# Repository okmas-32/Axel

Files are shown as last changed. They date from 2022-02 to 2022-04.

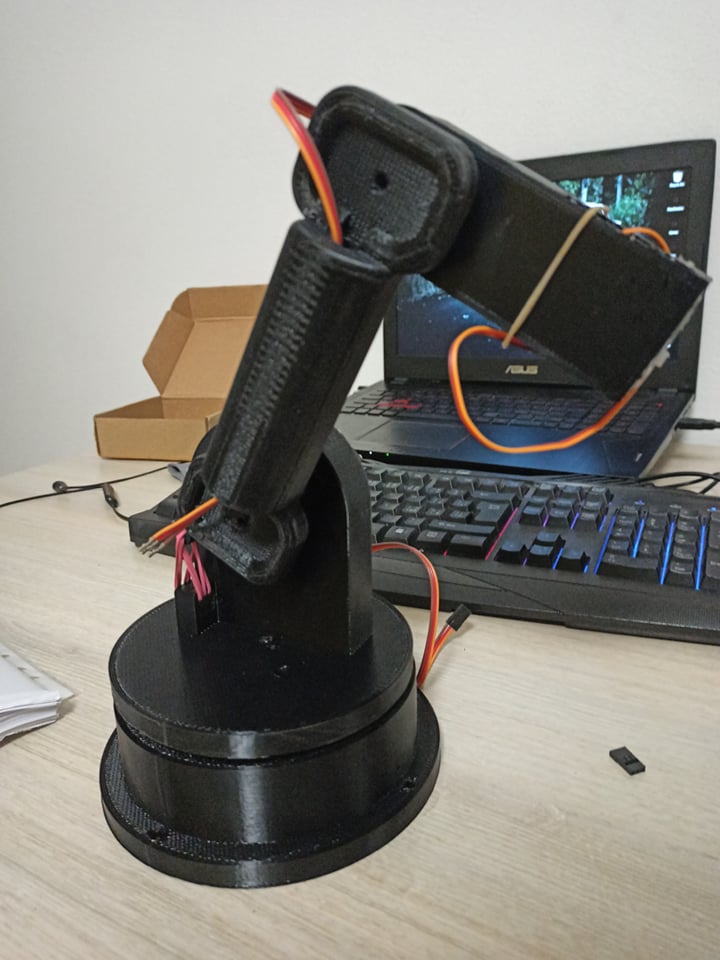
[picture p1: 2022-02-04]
3D_models/Angie_V1/Angie.jpg

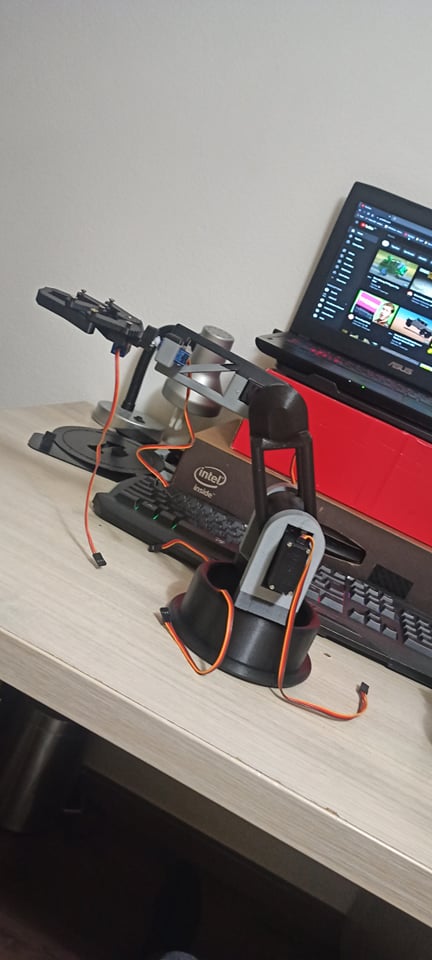
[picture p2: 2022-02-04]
3D_models/Bimbis_V2/Bimbis.jpg

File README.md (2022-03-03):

# Axel

It's our (me and my friend) graduation project about 3D printed robotic hands and they controlled by RaspberryPi-Arduino combo

we are using:
1. Raspberry Pi 3 b+		[`link`](https://www.raspberrypi.com/products/raspberry-pi-3-model-b-plus/) *1
1. Arduino Uno		[`link`](https://techfun.sk/produkt/arduino-uno-r3-precizny-klon/)  *2
1. Arduino Nano			[`link`](https://techfun.sk/produkt/arduino-nano-precizny-klon/)  *1
1. Servo motorček SG90		[`link`](https://techfun.sk/produkt/servo-motorcek-sg90/)   *3
1. Servo motorček MG996R	[`link`](https://techfun.sk/produkt/servo-motorcek-mg996r/) *7 
1. Buttons			[`link`](https://techfun.sk/produkt/tlacidlo-pbs-110-momentove-normalne-otvorene/)  *5
1. 2 axis joystick		[`link`](https://techfun.sk/produkt/joystick-2-osi-analogovy-vystup/) *2

how i set up Raspberry pi and its hotspot in RP_info.txt

python code works on linux and on windows (i dont know about mack)

how [`Angie`](/3D_models/Angie_V1/Angie.jpg) looks like :raised_hand_with_fingers_splayed:

how [`Bimbis`](/3D_models/Bimbis_V2/Bimbis.jpg) looks like :mechanical_arm:

---

Dominik Mankovický,
Samuel Čápek

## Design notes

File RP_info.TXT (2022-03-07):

všetok aktuálny kód je na stránke https://github.com/okmas-32/Axel

postup:

	nainštalovanie:
		pythonu 3.9.5:
			https://itheo.tech/install-python-39-on-raspberry-pi

		mounting USB:
			https://raspberrytips.com/mount-usb-drive-raspberry-pi/

		pip3.9:
			popen
			serial
			pyserial (kvôli serial.tools.list_ports ale to nefungovalo na raspberry tak som nakoniec použil popen)

-note: musel som spraviť work around lebo žiadna knižnica mi nevypíše výrobcu každého USB pripojeného zariadenia tak som spravil to že napíšem každému zariadeniu a to ktoré správne odpovie naspäť bude brané ako Arduino

	wireless access point (wireless controll):
		https://www.raspberryconnect.com/projects/65-raspberrypi-hotspot-accesspoints/158-raspberry-pi-auto-wifi-hotspot-switch-direct-connection
		-ssid: AXEL_WiFi (2)
		-pass: (take iste ako ssh heslo)

	joistick (do budúcna):
		https://iot-guider.com/raspberrypi/analog-joystick-module-in-raspberry-pi/attachment/interfacing-analog-joystick-module-in-raspberry-pi/

impruve:
	stránka
	Bézier Curve (3 bodové krivky ktoré sa tiež používajú na zobrazovanie fondow)
		-GIF		https://ambrosiogabe.github.io/assets/images/mathBehindFonts/bezierMath.gif
		-stránka	https://ambrosiogabe.github.io/the-math-behind-font-rasterization/
		-video		https://www.youtube.com/watch?v=LaYPoMPRSlk
	tutorial na pomali vsetko co treba vylepsit:
		-https://www.societyofrobots.com/robot_arm_tutorial.shtml

	viem že je možné z Raspberry pi programovať Arduino neskôr sa na to pozriem

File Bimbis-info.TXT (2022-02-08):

dĺžky:
	Base:		52mm
	Waist:		65mm
	Arm1:		150mm
	Arm2:		115mm
	Nastroj:	100mm

servo note:
	dve servá sú oproti sebe tak jedno z nich terba rozlíšiť (nazval som ho angry twin) a tomu servu treba prepočítať uhol "opačne" oproti jeho normálnej dvojičke vzhľadom k ich maximu (čo je 180°)
	v realite je servo označené bielymi botkami
	inými slovami:
		servo twin write(pos)
		servo angry_twin write(180 - pos)

motory (servos):

	Servo Motor MG996R (4ks)
		Operating Voltage is +5V typically
		Running Current:	500-900mA (6V)
		Stall Current:		2.5A (6V)
		Stall Torque: 		9.4 kg/cm (at 4.8V)
		Maximum Stall Torque: 	11 kg/cm (6V)
		Operating speed:	0.17 s/60° (1°/~3ms)
		Gear Type: 		Metal
		Rotation: 		0°-180°
		Weight of motor: 	55gm
	
	Servo Motor Micro SG90 (1ks)
		Voltage:		4.8-6VDC  (5V Typical)
		Current (stall):	360mA (measured) (idle 10mA)
		Stall Torque:		1.7 kg-cm (measured)
		Operating Speed:	0.12s / 60° (varies with VDC)
		Gear Type: 		Plastic
		Rotation: 		0°-180°

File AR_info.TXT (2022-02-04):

arduino je použité ako ovládač hardwaru... to jesť samotné servá na ruke

v programe som nikde nepoužil delay() dôvod:	
	-zastavý to celé arduino na dobu ktorý mu dám
	-radšej som si spravil vlastnú 
	-radšej som si spravil vlastnú funkciu ckaj()

musel som použiť baudrate 115200 inak by to nestíhalo taký veľký nával dát naraz (posielam cca 40ch raz a potom čakám)

!!!Arduino nano používa ATmega328P (old bootloader)

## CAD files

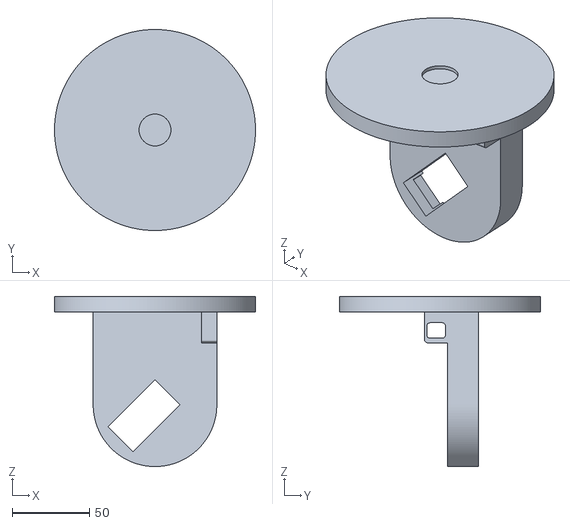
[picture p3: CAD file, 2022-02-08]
3D_models/Angie_V1/Waist.stl
130.0 x 130.0 x 110.0

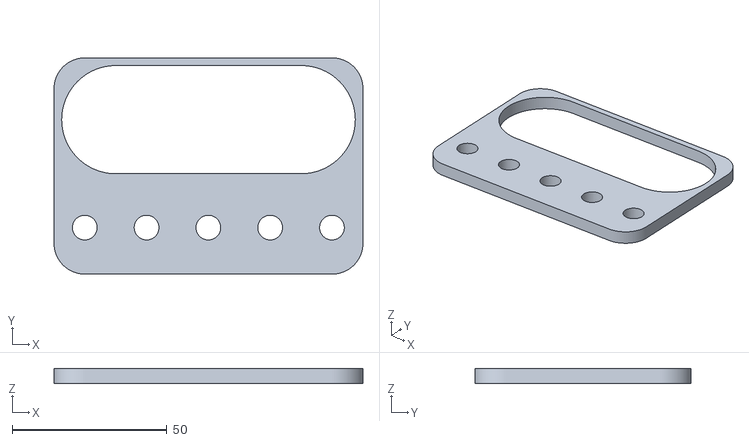
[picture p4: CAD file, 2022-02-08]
3D_models/Auxiliary_Stuff/Joy_housing_top.stl
100.0 x 70.0 x 5.00

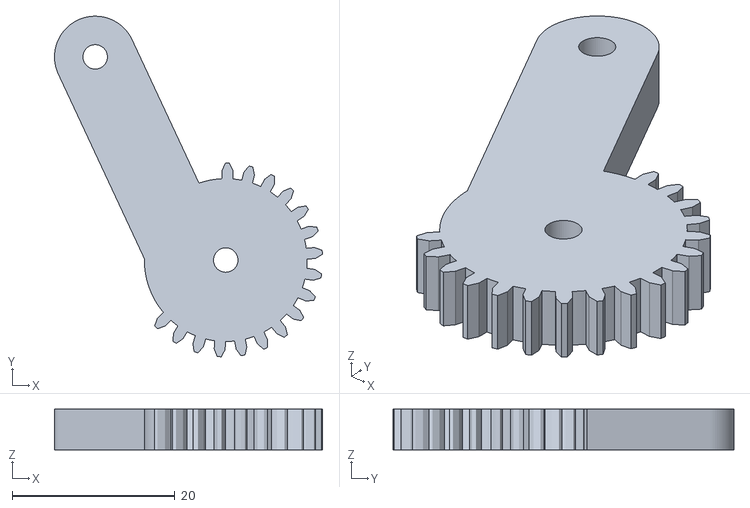
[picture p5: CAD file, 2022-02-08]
3D_models/Bimbis_V2/Gripper/Gripper Gear.stl
32.9 x 41.8 x 5.00

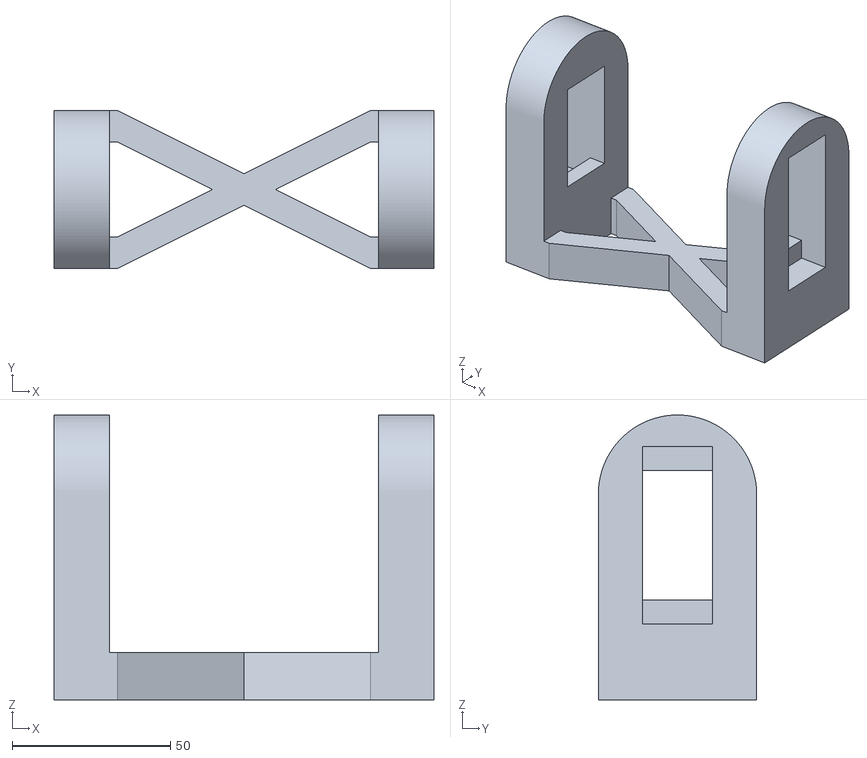
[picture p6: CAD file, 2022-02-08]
3D_models/Bimbis_V2/Waist.stl
120.0 x 50.0 x 90.0

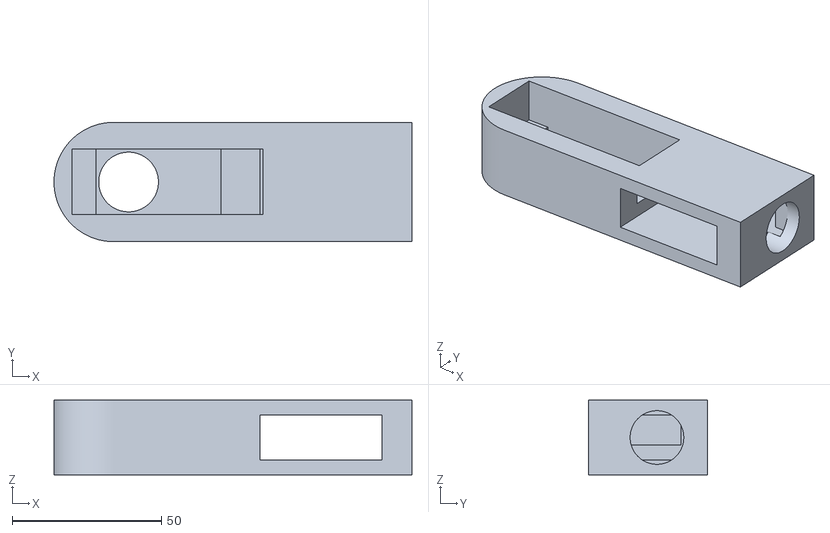
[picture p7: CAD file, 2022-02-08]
3D_models/Angie_V1/Forearm.stl
120.0 x 40.0 x 25.0

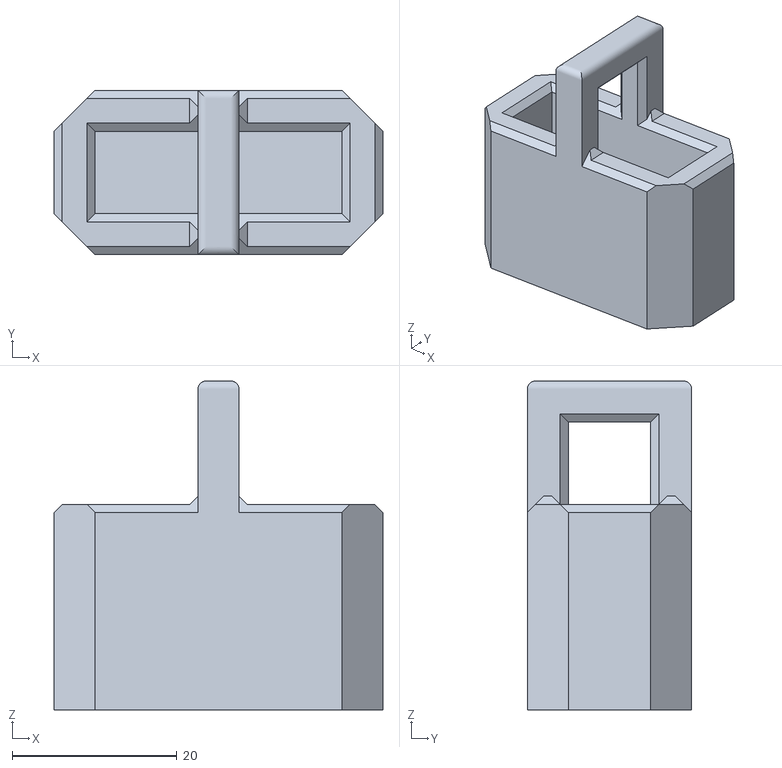
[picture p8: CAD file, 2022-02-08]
3D_models/Auxiliary_Stuff/A focking bocket.stl
40.0 x 20.0 x 40.0

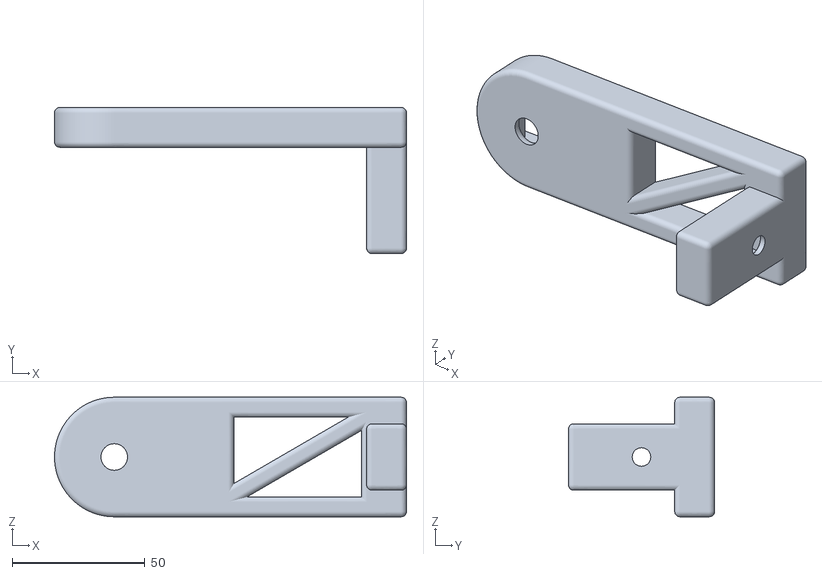
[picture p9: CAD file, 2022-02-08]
3D_models/Bimbis_V2/Forearm.stl
132.5 x 55.0 x 45.0

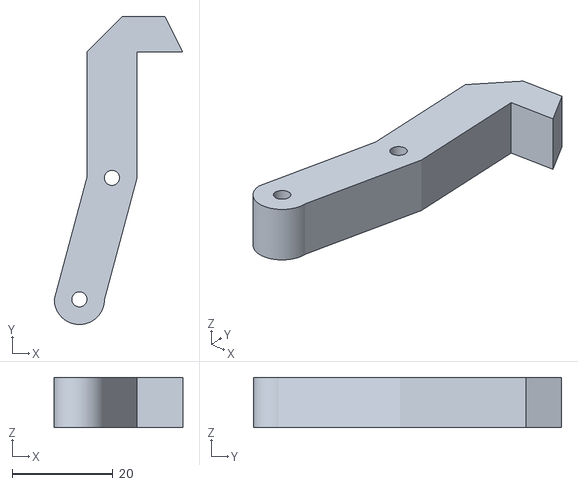
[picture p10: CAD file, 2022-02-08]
3D_models/Bimbis_V2/Gripper/Gripper claw2.stl
25.5 x 61.2 x 10.0

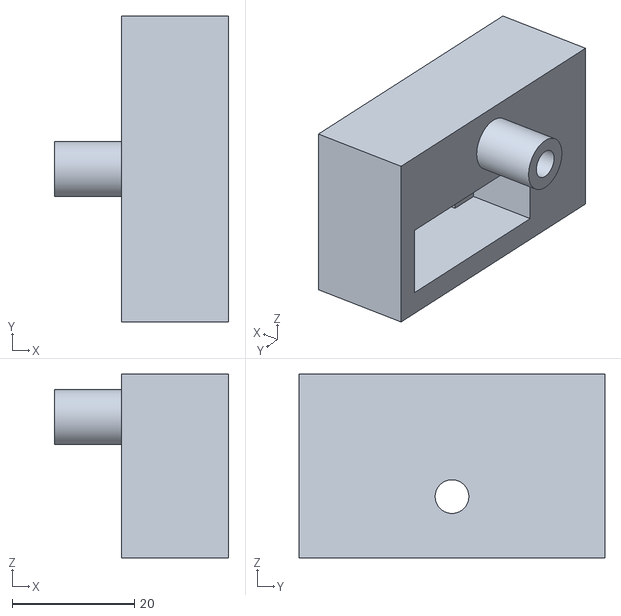
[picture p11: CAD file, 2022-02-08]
3D_models/Angie_V1/Gripper base.stl
28.5 x 50.0 x 30.0

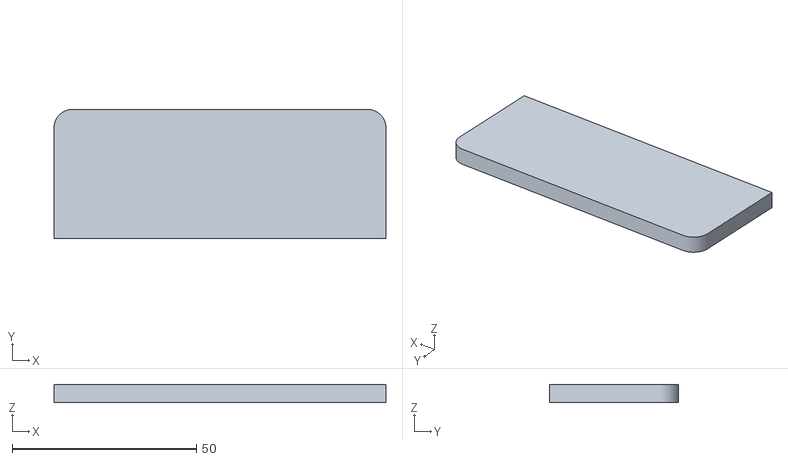
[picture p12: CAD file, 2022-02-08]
3D_models/Auxiliary_Stuff/Joy_spacer.stl
90.0 x 35.0 x 5.00

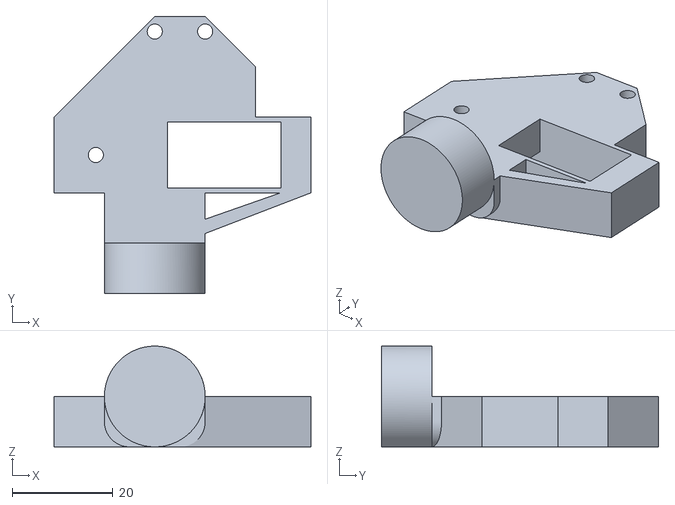
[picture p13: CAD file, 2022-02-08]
3D_models/Bimbis_V2/Gripper/Gripper base.stl
51.0 x 55.0 x 20.0

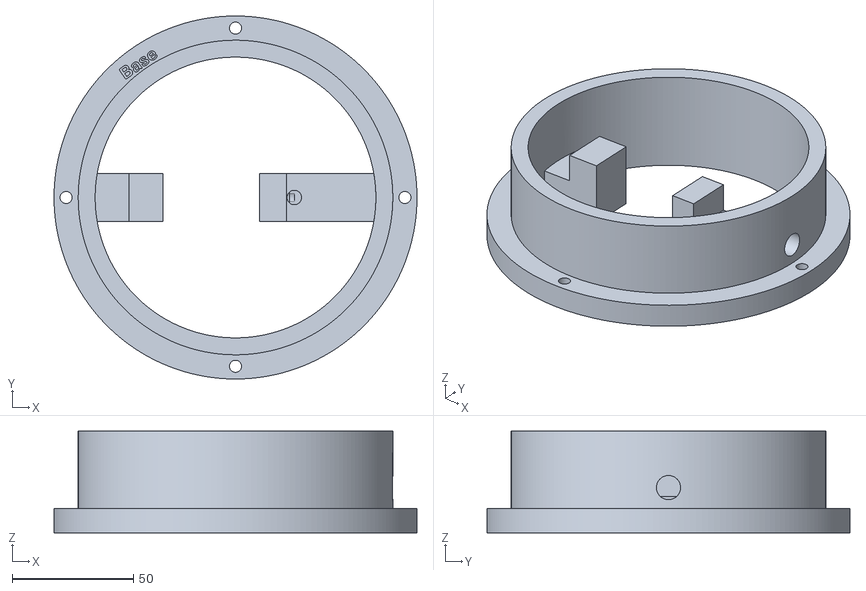
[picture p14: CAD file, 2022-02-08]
3D_models/Angie_V1/BAse.stl
150.0 x 150.0 x 42.0

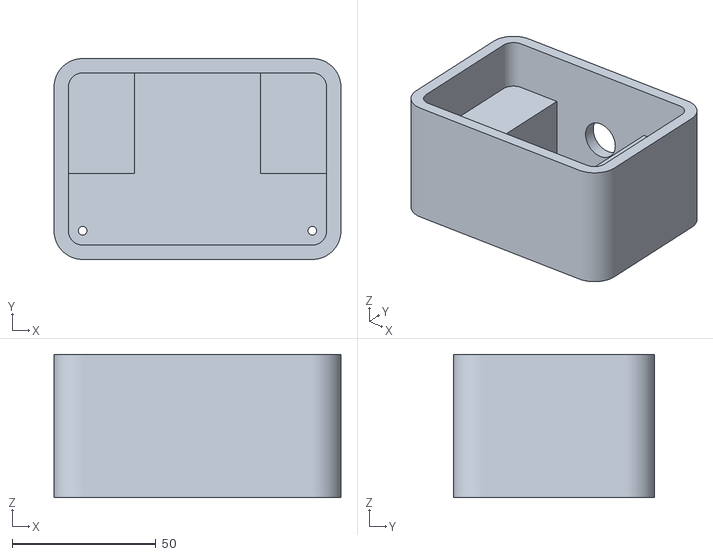
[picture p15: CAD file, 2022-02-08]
3D_models/Auxiliary_Stuff/Joy_housing.stl
100.0 x 70.0 x 50.0

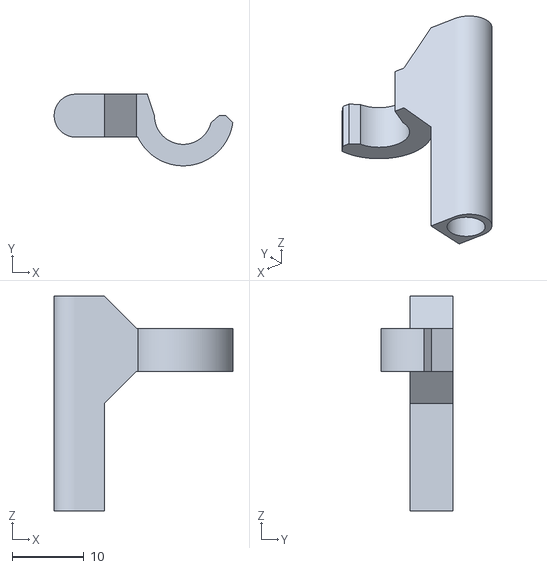
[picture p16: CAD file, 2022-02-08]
3D_models/Angie_V1/Gripper hook.stl
24.9 x 10.00 x 30.0

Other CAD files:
3D_models/Bimbis_V2/Gripper/Gripper claw.stl
3D_models/Bimbis_V2/Gripper/Griper gear 2.stl
3D_models/Bimbis_V2/Gripper/Gripper link 2.stl
3D_models/Bimbis_V2/Gripper/Gripper link.stl

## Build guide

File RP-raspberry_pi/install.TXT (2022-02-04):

pip install serial-tool
pip install serial

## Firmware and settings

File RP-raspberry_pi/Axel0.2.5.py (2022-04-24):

import subprocess
import sys
import serial
import serial.tools.list_ports  # python -m serial.tools.list_ports -v
import time
import locale
from math import sqrt, atan2, degrees
from csv import DictReader

baud_rate = 115200
spacer = ","

# TODO spraviť nejakú funkciu na debug
debug = {
	'0':            bool(1),  # celkový debug
	'csv':          bool(1),  # čítanie CSV súboru
	'math':         bool(1),  # matematika
	'mathEX':       bool(0),  # matematika
	'ini':          bool(1),  # inicializačný
	'fromser':      bool(1),  # z sériového portu
	'auto-program': bool(1),  # proste automatický mód
	'zasielanie':   bool(1),  # kontrola zasielania
	'text':         '\x1b[1;33;33m' + 'debug:' + '\x1b[0m',  # samotný text "debug:"
	'space':        '\x1b[1;33;33m' + 'I ' + '\x1b[0m',  # žltý medzerník
	'gtext':        '\33[92m' + 'I ' + '\33[0m',  # zelený medzerník
	'Error':        '\x1b[1;30;41m' + '\tE ' + '\x1b[0m'  # VEĽKÉ červené "E "
}


class OSErr(OSError):
	pass


class CustomError(Exception):
	"""môj vlastný error handler.. spravil som ho hľavne kvôli tomu
     aby som vedel zachitiť errori ale aj kvôli tomu že to bola sranda naprogramovať"""

	# zachitím error a vypíšem ho bez toho aby som musel zastaviť celí
	# program a robiť odznova celú inicializáciu a podobne

	# teda ak je to error ktorý som schopný obýsť.. ak to je niečo fatálnejšie tak to crashne celé
	def __init__(self, exception, i=None):
		if i != None:
			# ak to je očakávaný error (bez veľkého červeného E na začiatku)
			print('\r' + debug['space'] + str(exception))
		else:
			i = None
			print('\r' + debug['space'] + debug['Error'] + str(exception))
		pass


def tiME(func):
	def MYtiME(*args, **kwargs):
		t1 = time.time()
		nic = func(*args, **kwargs)
		t2 = time.time()
		print('\033[33m' + f'Function {func.__name__!r} executed in {(t2 - t1):.4f}s' + '\033[0m' + '\r\n')
		return nic

	return MYtiME


def wrapp(func):
	def MYwrapp(*args, **kwargs):
		print('\033[36m' + '*' * 20 + '\033[0m')
		func(*args, **kwargs)
		print('\033[36m' + '*' * 20 + '\033[0m')

	return MYwrapp


class Axel():
	def __init__(self, poss):
		"""tu si iba určím aké parametre bude držať objekt v
        classe Axel ako napr. port v ktorom je Arduino alebo dĺžku ramena ruky"""

		self.u1 = 0
		self.u2 = 0
		self.u3 = 0
		self.u4 = 0

		# ports in string
		self.Aport = False
		self.Bport = False
		self.joyPort = False

		self.notAxel = []

		self.pos1 = {}
		self.pos2 = {}

		if __name__ == "__main__":  # prečíta automaticky csv len ak je spustený ako hlavný program
			self.CSVr(poss)

			if debug['csv']:
				print(debug['gtext'] + debug['text'] + f' CSV-saved↓ \r')
				print(f'\t{self.pos1}')
				print(f'\t{self.pos2}')
				print(f'počet príkazov z CSV pre 1: {len(self.pos1)}')
				print(f'počet príkazov z CSV pre 2: {len(self.pos2)}')
				print('\r')

		self.X = 300
		self.Y = 250
		self.Z = 0

	# inicializácia
	# self.ini()

	# toto mám iba na testovanie Arduina
	#                      ↓↓ čas na pohyb v milisekundách
	# -3689,7823,14682,25,500
	# -3689,7823,14682,25,25,500

	# self.mathAX2(self.X, self.Y, self.Z, 143, 96, 7)

	def mathAX2(self, Xi, Yi, Zi, arm1, arm2, tool, base, Xbase=0, Ybase=0, Zbase=0):
		"""matika na výpočet uhlov z súradníc pre 2kĺbového robota + výpočet rotácie základne
         s Z (roboj je v zmysle že je položený a pracovnú plochu má okolo seba)"""
		# TODO niekedy optimalizovať
		# TODO spraviť pre celé pracovisko (offsety)

		# note base predpokladám že bude súčet base a waist (pre matiku to je v podsatate iba offset od "zeme")
		if debug['math'] and debug['mathEX']:
			print(debug['text'] + f' Matika-neznáme↓')
			print(f'\t_X = {Xi}')
			print(f'\t_Y = {Yi}')
			print(f'\t_Z = {Zi}')
			print(f'\tbase = {base}')
			print(f'\tarm1 = {arm1}')
			print(f'\tarm2 = {arm2}')
			print(f'\ttool = {tool}')

		if Xi < 80:
			Xi = 80
		if Yi < 80:
			Yi = 1
		if Zi < 1 - base:
			Zi = 80

		X = int(Xi)
		Y = int(Yi) - (base)
		Z = int(Zi)
		# vypočítam si dĺžky na výpočet matematiky
		dlzka1 = arm1
		dlzka2 = arm2 + tool
		# skontrolovanie či sú všetky súradnice v dosahu ak nie tak ich prepíše na najbližšie v dosahu
		# TODO spraiviť dosah automaticky vypočítaný nie manuálne napísaný

		# TODO spraviť Q_sq.... cool stuff ;)

		# main math
		t = dlzka2 ** 2 - dlzka1 ** 2 - X ** 2 - Y ** 2
		a = 4 * (X ** 2 + Y ** 2)
		b = 4 * Y * t
		c = t ** 2 - 4 * dlzka1 ** 2 * X ** 2
		D = b ** 2 - 4 * a * c
		Yb1 = (((-b) + sqrt(abs(D))) / (2 * a))
		Yb2 = (((-b) - sqrt(abs(D))) / (2 * a))
		Xb1 = (-sqrt(dlzka2 ** 2 - (Y - Yb1) ** 2) + X)
		Xb2 = (-sqrt(dlzka2 ** 2 - (Y - Yb2) ** 2) + X)
		if Yb1 >= Yb2:
			Xb = Xb1
			Yb = Yb1
		else:
			Xb = Xb2
			Yb = Yb2
		# debug stuff
		if debug['math'] and debug['mathEX']:
			print(debug['text'] + 'Matika-výpočet')
			print(f'\tX= {X}')
			print(f'\tY= {Y}')
			print(f'\tZ= {Z}')
			print(f'\tdlzka1= {dlzka1}')
			print(f'\tdlzka2= {dlzka2}')
			print(f'\n\tT= {t}')
			print(f'\ta= {a}')
			print(f'\tb= {b}')
			print(f'\tc= {c}')
			print(f'\tD= {D}')
			print(f'\t\tYb1= {Yb1}')
			print(f'\t\tYb2= {Yb2}')
			print(f'\t\tXb1= {Xb1}')
			print(f'\t\tXb2= {Xb2}\r')
			print(f'\tXb= {Xb}')
			print(f'\tYb= {Yb}')
		# konečná matematika
		beta = degrees(atan2(Yb, Xb))
		# nemam tucha prečo ale musí to byť takto s beta_ lebo inak to dáva iné divné čísla
		gama_ = degrees(atan2(Y - Yb, X - Xb))
		gama = gama_ - beta + 180

		deltaZ = (Z - Zbase) ** 2
		deltaX = (X - Xbase) ** 2
		dlzka = ((((X) - Xbase) ** 2) + ((Z - Zbase) ** 2)) ** (1 / 2)
		rad = atan2(deltaZ, deltaX)
		alfa = degrees(rad)

		if Z < 0:
			alfa = alfa * (-1)
		# alfa_ = atan(abs(Z) / X)
		# alfa = degrees(alfa_)

		# kontrolovanie či Z súradnica je v negative ak tak sa prehodí aj uhol lebo matika je spravená aby počítala iba s kladným Z
		# if Z<0:
		#     alfa = -alfa
		if debug['math']: print(
				debug['text'],
				str(alfa),
				str(beta),
				str(gama)
		)
		return alfa, beta, gama

	def CSVr(self, csvfile):
		"""Na čítanie z .csv filov"""

		with open(csvfile, 'r') as csvf:
			csv_diktionary = DictReader(csvf)

			if debug['csv']: print(debug['gtext'] + debug['text'] + f' CSV↓ \r')

			posCount1 = 0
			posCount2 = 0
			for row1 in csv_diktionary:
				if debug['csv']: print(row1)
				if row1['ar'] == '1':
					posCount1 += 1
					self.pos1[posCount1] = {
						'X': float(row1['X']),# * 10,
						'Y': float(row1['Y']),# * 10,
						'Z': float(row1['Z'])# * 10
					}
					if debug['csv']: print(self.pos1)

				if row1['ar'] == '2':
					posCount2 += 1
					self.pos2[posCount2] = {
						'X': float(row1['X']),# * 10,
						'Y': float(row1['Y']),# * 10,
						'Z': float(row1['Z'])# * 10
					}
					if debug['csv']: print(self.pos2)

				else:
					pass

				if debug['csv']: print(debug['gtext'] + f' {row1}')

		if debug['csv']: print('\r')
		return

	def autoMove(self, loop=1):
		zap_grip = [0, 0]  # zápästie a gripper "zatvorenosť"
		hook = 0  # hook / gripper? / hák
		while loop:
			for i in self.pos1:
				if debug['auto-program']:
					print(f'číslo pohybu = {i}')
					print(f'Suradnice 1: {self.pos1[i]}')
					print(f'Suradnice 2: {self.pos2[i]}')
				# výpočty uhlov
				alfa1, beta1, gama1 = self.mathAX2(self.pos1[i]['X'],
				                                   self.pos1[i]['Y'], self.pos1[i]['Z'],
				                                   self.Angi.parametre['info']['arm1'],
				                                   self.Angi.parametre['info']['arm2'],
				                                   self.Angi.parametre['info']['tool'],
				                                   self.Angi.parametre['info']['waist'] +
				                                   self.Angi.parametre['info']['base']
				                                   )
				alfa2, beta2, gama2 = self.mathAX2(self.pos2[i]['X'],
				                                   self.pos2[i]['Y'], self.pos2[i]['Z'],
				                                   self.Angi.parametre['info']['arm1'],
				                                   self.Angi.parametre['info']['arm2'],
				                                   self.Angi.parametre['info']['tool'],
				                                   self.Angi.parametre['info']['waist'] +
				                                   self.Angi.parametre['info']['base']
				                                   )
				if self.Angi.sendData:
					self.Angi.sendData = False
					# zasielanie uhlov
					self.Angi.sendAxel([alfa1, beta1, gama1, hook])
				if self.Bimb.sendData:
					self.Bimb.sendData = False
					self.Bimb.sendAxel([alfa2, beta2, gama2, zap_grip[0], zap_grip[1]])
		if debug['auto-program']: print('\33[92m' + ' auto-program ukončený ' + '\33[0m')

	def ini(self):
		"""funkcia na získanie (inicializácie) portov v ktorých je Axel a získanie dát z Arduina o samotnej ruke
        (funguje aj vo windowse☺)"""
		# TODO https://stackoverflow.com/questions/58268507/how-define-a-serial-port-in-a-class-in-python
		# TODO https://python.hotexamples.com/examples/serial/Serial/write/python-serial-write-method-examples.html
		portsini = []
		ports = []
		# hľadá Arduína kým sú neni iniciované všetky
		while not ((self.Aport and self.Bport) and self.joyPort):
			# aktualizácia ports listu
			for port, _, _ in sorted(serial.tools.list_ports.comports()):
				ports.append(port)
			if debug['ini']: print('\033[34m' + f'porty v ini = {ports}' + '\033[0m')
			# debug stuuf (keď nenájde žiadne porty čo je divné)
			if not ports: CustomError("Nenašiel som žiadne porty na hľadanie Axela")
			if portsini != ports:
				# prejde cez všetky porty ktoré mu dá serial.tools.list_ports knižnica
				for i, p in enumerate(reversed(ports)):
					# debuug
					if debug['0']: print('\r\n' + str(i)), print(f'port: {p}')
					try:
						ser = serial.Serial(p, baud_rate, timeout=2)
						# uistím sa že port je otvorený
						if ser.isOpen():
							ser.close()
						ser.open()
						x = ser.readline().decode(locale.getpreferredencoding().rstrip()).rstrip()
						Ax = x.split(',')
						if debug['fromser']: print(f'z serioveho portu {Ax}')
						if Ax[1] == 'Angie':  # ak poslalo Arduino v riadku druhé (za ",") angie tak :
							# vypíšem debuuug že som našiel na "tomto" porte Angie
							if debug['0'] and debug['ini']: print(debug['gtext'] + f'{p} port pre {Ax[1]} Arduino')

							ser.close()
							start = [300, 150, 0]
							self.Angi = arduino.ruka(Ax, start, ser)
							self.Aport = True
						elif Ax[1] == 'Bimbis:)':  # ak je Bimbis tak spravím to isté ako pri Angie (lebo oboje sú ruky)
							if debug['0'] and debug['ini']: print(debug['gtext'] + f'{p} port pre {Ax[1]} Arduino')

							ser.close()
							start = [250, 250, 0]
							self.Bimb = arduino.ruka(Ax, start, ser)
							self.Bport = True
						elif Ax[1] == 'joy':
							# debuuuug
							if debug['0'] and debug['ini']: print(debug['gtext'] + f'{p} port pre {Ax[1]} Arduino')

							ser.close()
							self.Joy = arduino.joy(Ax, ser)
							self.joyPort = True
						else:
							ser.close()
						if debug['0'] and debug['ini']: print('\033[92m' + '--' * 20 + '\r\n' + '\033[0m')

					# vypíšem Error ak nejaký nastane.. aaa pokračuje :D
					except Exception as e:
						CustomError(e)
						pass

				# keď nenájde žiadne Axelovské Arduina
				if not ((self.Aport or self.Bport) or self.joyPort):
					print(debug['text'] + '\r' + debug['space'] + "Nenašiel som žiadne porty s Axel doskami")
					pass

				portsini = ports
			ports.clear()

			time.sleep(1)

		if ((self.Aport and self.Bport) and self.joyPort):
			# aby som si bol istý že sú otvorené oba porty
			if self.Angi.serPort.isOpen():
				self.Angi.serPort.close()
			self.Angi.serPort.open()
			if self.Bimb.serPort.isOpen():
				self.Bimb.serPort.close()
			self.Bimb.serPort.open()

			print('\r\n' + debug['gtext'] + debug['gtext'] + debug[
				'gtext'] + '\33[92m' + ' inicializácia Axel prostredia je ukončená' + '\33[0m' + '\r\n')


class arduino():
	class ruka():
		def __init__(self, parametre, zaklad, serPort=serial.Serial()):
			self.serPort = serPort
			self.serPort.open()
			if self.serPort.isOpen():
				self.serPort.close()
			self.serPort.open()
			self.serPort.flush()
			self.name = parametre[1]
			self.sendData = False

			if debug['ini']: print(parametre)
			self.parametre = {
				'info':      {
					'name':  str(parametre[1]),
					'base':  int(parametre[2]),
					'waist': int(parametre[3]),
					'arm1':  int(parametre[4]),
					'arm2':  int(parametre[5]),
					'tool':  int(parametre[6])
				},
				'suradnice': {
					'X': int(zaklad[0]),
					'Y': int(zaklad[1]),
					'Z': int(zaklad[2])
				},
				'uhly':      [
					0,
					0,
					0,
					0
				]
			}

			if self.name == 'Bimbis:)':  # pre gripper
				self.parametre['uhly'].append(0)

			self.parametre['uhly'][0], \
			self.parametre['uhly'][1], \
			self.parametre['uhly'][2] = \
				object.mathAX2(
						self.parametre['suradnice']['X'],
						self.parametre['suradnice']['Y'],
						self.parametre['suradnice']['Z'],
						self.parametre['info']['arm1'],
						self.parametre['info']['arm2'],
						self.parametre['info']['tool'],
						self.parametre['info']['base'] +
						self.parametre['info']['waist']
				)

			self.sendAxel(self.parametre['uhly'], 2000)

			if debug['ini'] and not self.sendData:
				print(
					debug['gtext'] +
					debug['gtext'] +
					f'inicializácia {parametre[1]} hotová\r\n'
				)


		@tiME
		def sendAxel(self, data, milis=1500):  # TODO dať do subprocess alebo aspoň do asyncu
			"""táto funkcia slúži na zasielanie uhlov a času za ktorý sa majú servá pohnúť do Axel Arduina"""
			# note používam prvú verziu AR-RAP

			self.sendData = False

			if debug['zasielanie']: print(f'\rdata v send Data = {data}')
			# zaokruhlenie(pre posledné servo čiže chnapačky) / zjednodušenie(aby som nemusel posielať desatinné čísla)
			# pri posielaní do sériového portu
			rou = 100
			serdata = "heh... you done it"
			if self.name == 'Angie':
				serdata = (
						str(round(int(data[0]), 2) * rou
						    if (int(data[0]) != 0)
						    else str(0))
						+ spacer +
						str(round(int(data[1]), 2) * rou
						    if (int(data[1]) != 0)
						    else str(0))
						+ spacer +
						str(round(int(data[2]), 2) * rou
						    if (int(data[2]) != 0)
						    else str(0))
						+ spacer +
						str(round(int(data[3]) / 180 * 100, 2)
						    if (int(data[3]) != 0)
						    else str(0))
						+ spacer +
						str(milis)
				)
				data.clear()
			elif self.name == 'Bimbis:)':
				serdata = (
						str((round(int(data[0]), 2) * rou)
						    if (int(data[0]) != 0)
						    else str(0))
						+ spacer +
						str((round(int(data[1]), 2) * rou)
						    if (int(data[1]) != 0)
						    else str(0))
						+ spacer +
						str((round(int(data[2]), 2) * rou)
						    if (int(data[2]) != 0)
						    else str(0))
						+ spacer +
						str(round(int(data[3]) / 180 * 100, 2)
						    if (int(data[3]) != 0)
						    else str(0))
						+ spacer +
						str(round(int(data[4]) / 180 * 100, 2)
						    if (int(data[4]) != 0)
						    else str(0))
						+ spacer +
						str(milis)
				)
				data.clear()
			else:
				CustomError("zasielanie dát: neviem kde ale musíš zadať správne arduino na ktoré chceš poslať dáta")
			if debug['zasielanie']: print(f'posielanie dat = {serdata}')
			while not self.sendData:
				self.serPort.write((serdata + '\r\n').encode(locale.getpreferredencoding().rstrip()))
				time.sleep((milis - 200) / 1000)
				self.serPort.flush()
				c = self.serPort.readline().decode(locale.getpreferredencoding().rstrip()).rstrip()
				if debug['auto-program']: print(f'pohyb dokončený z {self.name} Arduina?: {c}')
				if c == '1':
					self.sendData = True
					if debug['auto-program']:
						print('\033[36m' + '*' * 20 + '\033[0m')
						print(debug['gtext'] + f"pohyb dokončený")
						print('\033[36m' + '*' * 20 + '\033[0m')
				else:
					print('\x1b[1;33;33m' + 'čakanie na dokončenie pohybu' + '\x1b[0m')
					print(c + '\n')
					self.serPort.flush()

		def __exit__(self, exc_type=0, exc_val=0, exc_tb=0):
			if debug['0']: print('\x1b[1;30;41m' + f'zatvaram port {self.name} ' + '\x1b[0m')
			if self.serPort.isOpen():
				serdata = 'reset'
				self.serPort.write((serdata + '\r\n').encode(locale.getpreferredencoding().rstrip()))
				self.serPort.close()
			else:
				CustomError(f'Port {self.serPort.name} už bol zatvorený')

		def __str__(self):
			return str(self.__class__) + '\n' + '\n'.join(
					('{} = {}'.format(item, self.__dict__[item]) for item in self.__dict__))

	class joy():
		def __init__(self, parametre, serPort=serial.Serial()):
			self.serPort = serPort
			self.name = parametre[1]
			self.serPort.close()

			# iniciuje proces 1 (p1) ako clobálne a dá mu dubprocess s python programom
			# (joy_ReadCOM.py) + port a baud rate v ktorom pracujeme
			global p1
			p1 = subprocess.Popen(
					['python', './joy_ReadCOM.py', str(self.serPort.name), str(self.serPort._baudrate)],
					stdin=subprocess.PIPE,
					stdout=subprocess.PIPE, stderr=subprocess.PIPE)

			# keď je debug zapnutý tak vypíše 10 riadkov z subprocessu čo prečítal (proste či to ide)
			if debug['0'] and debug['ini']:
				for _ in range(10):
					rjoy = p1.stdout.readline().decode().rstrip()
					print(debug['gtext'] + f'joyAR says: {rjoy}')

			self.Parametre = {
				'name':   str(parametre[1]),
				'max':    int(parametre[2]),
				'dead':   int(parametre[3]),
				'center': int(int(parametre[2]) / 2)
			}

		def __exit__(self, exc_type=0, exc_val=0, exc_tb=0):
			if debug['0']: print('\x1b[1;30;41m' + f'zatvaram port {self.name} ' + '\x1b[0m')
			self.serPort.close()
			if self.serPort.isOpen():
				CustomError(f'Port {self.serPort.name} sa nepodarilo zatvoriť')

		def __str__(self):
			return str(self.__class__) + '\n' + '\n'.join(
					('{} = {}'.format(item, self.__dict__[item]) for item in self.__dict__)
			)


def manual():
	try:
		while True:
			X = int(input('zadaj X: '))
			Y = int(input('zadaj Y: '))
			Z = int(input('zadaj Z: '))
			print('\nzadaj číslo\n'
			      '0 = Angie\n'
			      '1 = Bimbis')
			choose = input('vyber robota: ')
			uhol = [0]*3
			if choose == '0':
				print('pohyb Angi')
				uhol[0], \
				uhol[1], \
				uhol[2] = \
					object.mathAX2(X,
					               Y,
					               Z,
					               object.Angi.parametre['info']['arm1'],
					               object.Angi.parametre['info']['arm2'],
					               object.Angi.parametre['info']['tool'],
					               object.Angi.parametre['info']['base'] +
					               object.Angi.parametre['info']['waist']
					               )
				uhol.append(0)

				object.Angi.sendAxel(uhol, 2000)

			if choose == '1':
				print('pohyb Bimbis')
				uhol[0], \
				uhol[1], \
				uhol[2] = \
					object.mathAX2(X,
					               Y,
					               Z,
					               object.Bimb.parametre['info']['arm1'],
					               object.Bimb.parametre['info']['arm2'],
					               object.Bimb.parametre['info']['tool'],
					               object.Bimb.parametre['info']['base'] +
					               object.Bimb.parametre['info']['waist']
					               )
				uhol.append(0)
				uhol.append(0)

				object.Bimb.sendAxel(uhol, 2000)

	except KeyboardInterrupt:
		print("\nzadaný Ctrl+C interupt")
		pass

# toto pôjde jedine ak to je spustené ako main program
if __name__ == "__main__":

	# spravý prvú inicializáciu celého prostredia

	zlom = 'ty máš Mac?? -.-'
	try:  # note v Raspberry sa musí vymeniť "\" za "/"... nepítaj sa prečo iba to sprav
		if sys.platform == 'win32':
			zlom = '\\'
		elif sys.platform.startswith('linux'):
			zlom = '/'
		else:
			raise OSErr

	except OSErr:
		print(debug['Error'] + 'tento program nepodporuje iné systémi ako Windows a Linux' + debug['Error'])
		print(zlom)
		sys.exit(1)

	object = Axel('.' + zlom + 'positions.csv')

	# inicializácia Axel prostredia
	object.ini()

	#object.autoMove(1)

	manual()


	# try:
	# 	pass
	#
	# except KeyboardInterrupt:  # očakáva Ctrl + C prerušenie programu
	# 	if debug['0'] and debug['ini']:
	# 		print('\r' + debug['text'])
	# 		object.Angi.__exit__()
	# 		object.Bimb.__exit__()
	# 		object.Joy.__exit__()
	# 		print(debug['space'] + f'Angie arduino je zatvorene: {not object.Angi.serPort.isOpen()}')
	# 		print(debug['space'] + f'Bimb arduino je zatvorene: {not object.Bimb.serPort.isOpen()}')
	# 		print(debug['space'] + f'joy arduino je zatvorene: {not object.Joy.serPort.isOpen()}')
	#
	# 	print(f'\nAxel bol zastavený s commandom Ctrl + C\n')
	#
	# 	sys.exit(1)
	#
	# except Exception as e:
	# 	if debug['0'] and debug['ini']:
	# 		print('\r' + debug['text'])
	# 		print(debug['space'] + f'Angie arduino je zatvorene: {not object.Angi.serPort.isOpen()}')
	# 		print(debug['space'] + f'Bimb arduino je zatvorene: {not object.Bimb.serPort.isOpen()}')
	# 		print(debug['space'] + f'joy arduino je zatvorene: {not object.Joy.serPort.isOpen()}')
	# 	raise CustomError(e)
	# # print(f'\nExeption: ({e})')
	#
	# finally:  # "čisté" ukončenie programu
	# 	if debug['0']:
	# 		print('\r')
	# 		print(debug['text'])
	# 		print(debug['space'] + str(object.Angi.name))
	# 		print(debug['space'] + str(object.Angi) + '\n')
	#
	# 		print(debug['space'] + str(object.Bimb.name))
	# 		print(debug['space'] + str(object.Bimb) + '\n')
	#
	# 		print(debug['space'] + str(object.Joy.name))
	# 		print(debug['space'] + str(object.Joy) + '\n')
	# 	sys.exit(0)  # "čisté" ukončenie programu

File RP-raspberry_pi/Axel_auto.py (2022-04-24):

from sys import exit
from serial import Serial, tools
import serial.tools.list_ports      # python -m serial.tools.list_ports -v
from time import sleep
from locale import getpreferredencoding
from math import sqrt, atan2, degrees, atan
from csv import DictReader

baud_rate = 115200

debug = {
    '0': bool(1),            # celkový debug
    'csv': bool(1),          # čítanie CSV súboru
    'math': bool(1),         # matematika
    'ini': bool(1),          # inicializačný
    'fromser': bool(0),      # z sériového portu
    'text': '\x1b[1;33;33m' + 'debug:' + '\x1b[0m',     # samotný text "debug:"
    'space': '\x1b[1;33;33m' + 'I ' + '\x1b[0m',        # žltý medzerník
    'gtext': '\33[92m' + 'I ' + '\33[0m',               # zelený medzerník
    'Error': '\x1b[1;30;41m' + '\tE ' + '\x1b[0m'       # VEĽKÉ červené "E "
}


class CustomError(Exception):
    """môj vlastný error handler.. spravil som ho hľavne kvôli tomu
     aby som vedel zachitiť errori ale aj kvôli tomu že to bola sranda naprogramovať"""

    # zachitím error a vypíšem ho bez toho aby som musel zastaviť celí
    # program a robiť odznova celú inicializáciu a podobne

    # teda ak je to error ktorý som schopný obýsť.. ak to je niečo fatálnejšie tak to crashne celé
    def __init__(self, exception, i=None):
        if i is not None:
            # ak to je očakávaný error (bez veľkého červeného E na začiatku)
            print('\r' + debug['space'] + str(exception))
        else:
            i = None
            print('\r' + debug['space'] + debug['Error'] + str(exception))
        pass


class Axel():
    def __init__(self):
        """tu si iba určím aké parametre bude držať objekt v
        classe Axel ako napr. port v ktorom je Arduino alebo dĺžku ramena ruky"""

        self.u1 = 0
        self.u2 = 0
        self.u3 = 0
        self.u4 = 0

        self.ar1u1 = 45
        self.ar1u2 = 45
        self.ar1u3 = 45
        self.ar1u4 = 0

        self.ar2u1 = 45
        self.ar2u2 = 45
        self.ar2u3 = 45
        self.ar2u4 = 90
        self.ar2u5 = 90

        self.A = Serial()        # ser. pre Angie
        self.B = Serial()        # ser. pre Bimbisa
        self.joy = Serial()      # ser. pre joystick ale aj tak sa nepoužíva lebo ho zapína subprocess

        #ports in string
        self.Aport = None
        self.Bport = None
        self.joyPort = None

        #parameters in dictionary
        self.AParametre = {}
        self.BParametre = {}
        self.joyParametre = {}

        self.sendData = bool(1)
        self.sendData1 = bool(1)


        #baud rate for all Arduinos
        self.baud_rate = baud_rate

        self.notAxel = []

        self.spacer = ","

        self.pos = None
        self.pos1 = None

        # self.ini()

        if __name__ == "__main__":
            # čítanie z CSV
            # p = glob(".\*.csv")
            # csv = str(p[0])
            # while True:
            #     time.sleep(5)
            self.pos = self.CSVr('.\positions.csv')
            self.pos1 = self.CSVr('.\positions1.csv')

            if debug['csv']:
                print(debug['gtext'] + debug['text'] + f' CSV-saved↓ \r')
                print(f'\t{self.pos}')
                print(f'\t{self.pos1}')
                print('\r')

        # self.mathAX2(90, 90, 0, 143, 96, 7)

        self.X = 90
        self.Y = 90
        self.Z = 0
        self.rjoy = None

    def ini(self):
        """funkcia na získanie (inicializácie) portov v ktorých je Arduino a získanie dát z Arduina o samotnej ruke
        (funguje aj vo windowse☺)"""

        portsini = []
        for port, _, _ in sorted(tools.list_ports.comports()):
            portsini.append(port)

        # hľadá Arduína kým sú neni pripojené všetky
        while not (self.Aport and self.Bport):  # počká sekundu potom skontroluje či sú nové porty ak tak skontroluje či sú to Arduiná s Axelom

            sleep(1)
            print("čakám na pripojenie Arduín")
            ports = list(tools.list_ports.comports())

            # debug stuuf (keď nenájde žiadne porty)
            if not portsini:
                raise CustomError("Nenašiel som žiadne porty na hľadanie Axela", 1)
                pass

            if portsini != ports:
                portEH = []

                # prejde cez všetky porty ktoré mu dá serial.tools.list_ports knižnica
                for i, p in enumerate(reversed(ports)):

                    # hodí ich do stringu, splitne a zoberie si prvú hodnotu z toho splitu (to býva ten prvý port)
                    port = str(p)
                    p = port.split(' ', 1)
                    portEH.append(p[0])

                    # debuug
                    if debug['0']:
                        print(str(i))
                        print(f'port: {port}')

                    ser = Serial(portEH[i], self.baud_rate, timeout=2)

                    if ser.isOpen():
                        ser.close()
                    ser.open()

                    try:
                        x = ser.readline().decode(getpreferredencoding().rstrip()).rstrip()

                        Ax = x.split(',')

                        if Ax[1] == 'Angie':  # ak poslalo Arduino v riadku druhé (za ",") angie tak :

                            # vypíšem debuuug že som našiel na "tomto" porte Angie
                            if debug['0'] and debug['ini']: print(debug['gtext'] + f'{portEH[i]} Angie Arduino')

                            # uložím seriový port (zavriem ten starý otvorým ten nový), port (ako text) a samotné parametre
                            # danej ruky (všetky dĺžky a meno)
                            self.A = ser
                            ser.close()
                            self.A.open()
                            self.Aport = portEH[i]
                            self.AParametre = {
                                'name':  str(Ax[1]),
                                'base':  int(Ax[2]),
                                'waist': int(Ax[3]),
                                'arm1':  int(Ax[4]),
                                'arm2':  int(Ax[5]),
                                'tool':  int(Ax[6])
                            }
                        if Ax[1] == 'Bimbis:)':  # ak je Bimbis tak spravím to isté ako pri Angie (lebo oboje sú ruky)
                            if debug['0'] and debug['ini']: print(debug['gtext'] + str(portEH[i]) + f' Bimbis Arduino')
                            self.B = ser
                            ser.close()
                            self.B.open()
                            self.Bport = portEH[i]
                            self.BParametre = {
                                'name':  str(Ax[1]),
                                'base':  int(Ax[2]),
                                'waist': int(Ax[3]),
                                'arm1':  int(Ax[4]),
                                'arm2':  int(Ax[5]),
                                'tool':  int(Ax[6])
                            }
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

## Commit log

2022-02-08 servo management complet
2022-02-10 buttons on joy
2022-02-11 readme update2
    [A focking bocket.stl, BAse.stl, Forearm.stl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]
2022-02-15 csv file read
    [positions.csv]
2022-02-15 finish Arduino end and double checkt it
2022-02-16 test Raspberry
2022-02-17 no time
    [positions1.csv]
2022-02-26 long time gone
    [positions.csv, positions1.csv]
2022-02-28 rp test
    [positions.csv, positions1.csv]
2022-02-28 correction of csv file
    [positions1.csv]
2022-03-01 fully working init
    [positions.csv]
2022-03-03 commit good?
    [positions.csv]
2022-04-24 not continuing movement
    [positions.csv]
2022-04-24 manual demo
    [positions.csv]
